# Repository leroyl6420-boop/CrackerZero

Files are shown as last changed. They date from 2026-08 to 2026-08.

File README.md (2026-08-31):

# CrackerZero
A portable, Raspberry Pi 0-powered cyberdeck! My first cyberdeck too (: it's thin and light like a cracker

The Cracker Zero will be my first cyberdeck! The reason as to why I chose a Pi 0 instead of a Pi 4 or 5 is because I wanted extra space and budget to make a custom keyboard. It'll be nothing fancy, just a couple of push buttons and a joystick on a perfboard, but I can say that it is my own (: I'm planning on running some kind of Linux.

# Wiring Diagram

Wiring diagram for the Pi:

| Left row | Function | Use | Right row | Function | Use |
|---:|---|---|---:|---|---|
| **1** | 3.3 V | SCREEN | **2** | 5 V | SCREEN / same 5 V rail as power input |
| **3** | GPIO 2 / SDA | SCREEN | **4** | 5 V | SCREEN / same 5 V rail as power input |
| **5** | GPIO 3 / SCL | SCREEN | **6** | GND | SCREEN |
| **7** | GPIO 4 | SCREEN | **8** | GPIO 14 / TXD | SCREEN |
| **9** | GND | SCREEN | **10** | GPIO 15 / RXD | SCREEN |
| **11** | GPIO 17 | SCREEN | **12** | GPIO 18 | SCREEN |
| **13** | GPIO 27 | SCREEN | **14** | GND | SCREEN |
| **15** | GPIO 22 | SCREEN | **16** | GPIO 23 | SCREEN |
| **17** | 3.3 V | SCREEN | **18** | GPIO 24 | SCREEN |
| **19** | GPIO 10 / MOSI | SCREEN | **20** | GND | SCREEN |
| **21** | GPIO 9 / MISO | SCREEN | **22** | GPIO 25 | SCREEN |
| **23** | GPIO 11 / SCLK | SCREEN | **24** | GPIO 8 / CE0 | SCREEN |
| **25** | GND | SCREEN | **26** | GPIO 7 / CE1 | SCREEN |
| **27** | GPIO 0 / ID_SD | Leave unused | **28** | GPIO 1 / ID_SC | Leave unused |
| **29** | GPIO 5 | Available | **30** | GND | Available |
| **31** | GPIO 6 | Available | **32** | GPIO 12 | Available |
| **33** | GPIO 13 | Available | **34** | GND | Available |
| **35** | GPIO 19 | Available | **36** | GPIO 16 | Available |
| **37** | GPIO 26 | Available | **38** | GPIO 20 | Available |
| **39** | GND | Available | **40** | GPIO 21 | Available |

A 22 AWG wire will be soldered onto the 5v wires from the TP4056 module. The GND will be soldered to one of the empty ground pins. I really wish they'd make the screen use only one 5V pin :P

Wiring diagram for the CH32X035 devboard keyboard:

| LEFT SIDE | USE | RIGHT SIDE | USE |
|---|---|---|---|
| 5V | USB power | GND | Ground |
| GND | Ground | PC19 | Unused |
| 3V3 | KY-023 VCC | PB12 | Button 1 |
| PA0 | Joystick X | PC18 | Unused |
| PA1 | Joystick Y | PB11 | Button 2 |
| PA2 | Joystick Click | PB3 | Button 3 |
| PA3 | Layer LED | PB1 | Button 4 |
| PA4 | Spare | PB0 | Button 5 |
| PA5 | Spare | PA7 | Button 6 |
| — | — | PA6 | Spare |

I chose not to CAD a case for the keyboard to get the see the art from Cyao on the CH32X035 :D

# CAD

There wasn't much CADing to do for the Cracker Zero! I just make sure that I knew where to put all the parts, here:

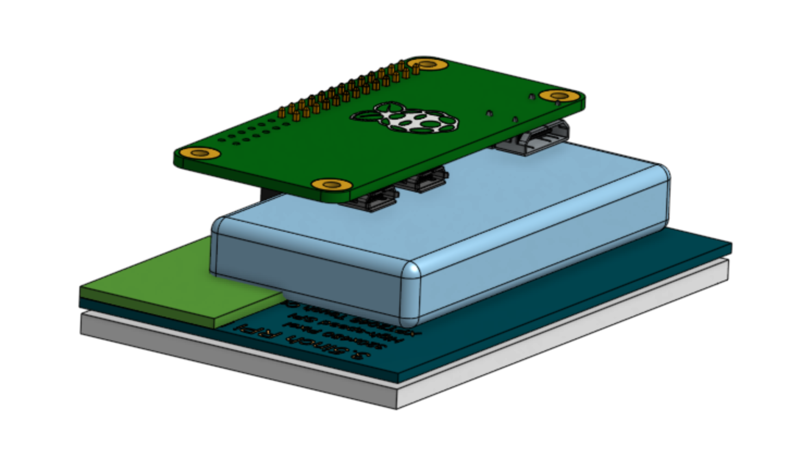
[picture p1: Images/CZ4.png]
An image of the caseless Cracker Zero


And I made a case for the Pi and the screen, here:

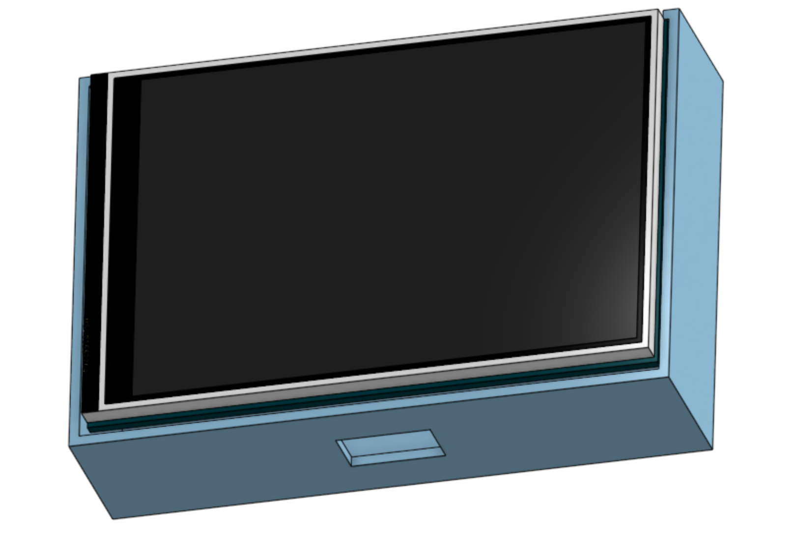
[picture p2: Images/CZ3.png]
The Cracker Zero in its case


Of course, I had to CAD the cute little keyboard

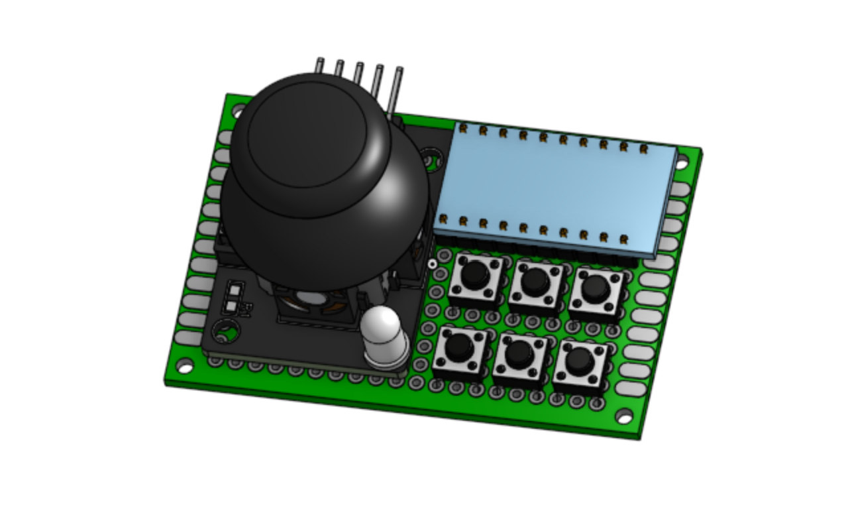
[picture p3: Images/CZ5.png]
An image of the Cracker Zero's custom keyboard


# Assembly

Assembling the Cracker Zero won't be very hard. Just find two 13-pin-long pin headers and solder them onto the first 13 pin slots of both rows on the Pi 0. Solder the Lipo's spliced wires onto the protection module's BAT+ and BAT- pads, and solder the protection module's Input/Output +/- pads to the TP4056 module's BAT+/- pins. Wire the TP4056's OUT+ to one of the Pi's 5V pins (using the latching button), and wire the OUT- to any of the Pi's GNDs. The Cracker Zero charges using micro USB (I know I know diabolical). Solder the keyboard according to the wiring diagram, and connect it to the Pi's data micro USB port using a USB-C to micro USB power/data cable. 

# AI Use

AI was used to find good parts/deals.

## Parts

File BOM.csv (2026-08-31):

Part | Quantity | Cost | Link
Raspberry Pi Zero W | 1 | $36.99 | https://www.amazon.com/EC-Buying-Pi-Zero-Development/dp/B0FN4CN7TM
ch32x035 Devboard | 1 | Already Owned
3.5 Inch 480x320 Display | 1 | $17.99 | https://www.amazon.com/Hosyond-480x320-Screen-Display-Raspberry/dp/B0BJDTL9J3
6x4cm Perfboard | 1 | $7.99 | https://www.amazon.com/Chanzon-Double-Sided-Board-Sizes/dp/B07LF78ZY3
USBC to Micro USB Cable | 1 | $5.69 | https://www.amazon.com/FEMORO-Adapter-Braided-Transfer-Compatible/dp/B0CMLS2MB1?hvadid=816679433751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
Latching Button | 1 | $9.98 | https://www.amazon.com/DMWD-12-Pack-Latching-Pre-soldered-Self-Locking/dp/B0D4D8DQJD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
Battery Protection Module | 1 | $5.99 | https://www.amazon.com/DIANN-Charger-Protection-Lithium-Battery/dp/B0B4D1D74V
Battery Charging Module | 1 | $9.89 | https://www.amazon.com/Battery-Charger-Discharge-Integrated-Lithium/dp/B098989NRZ
3.7v Lipo | 1 | $9.99 | https://www.amazon.com/JLJLUP-Rechargeable-Integrated-Protection-Development/dp/B0FH9XHXRT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
32GB Micro SD Card | 1 | $22.80 | https://www.amazon.com/SanDisk-Ultra%C2%AE-microSDHC-120MB-Class/dp/B08L5HMJVW
22AWG Solid Core Wire | N/A | $11.98 | https://www.amazon.com/BNTECHGO-Electric-Gauge-Tinned-Copper/dp/B07JMVX22G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
Tax |  | $11.18
Total |  | $155.46

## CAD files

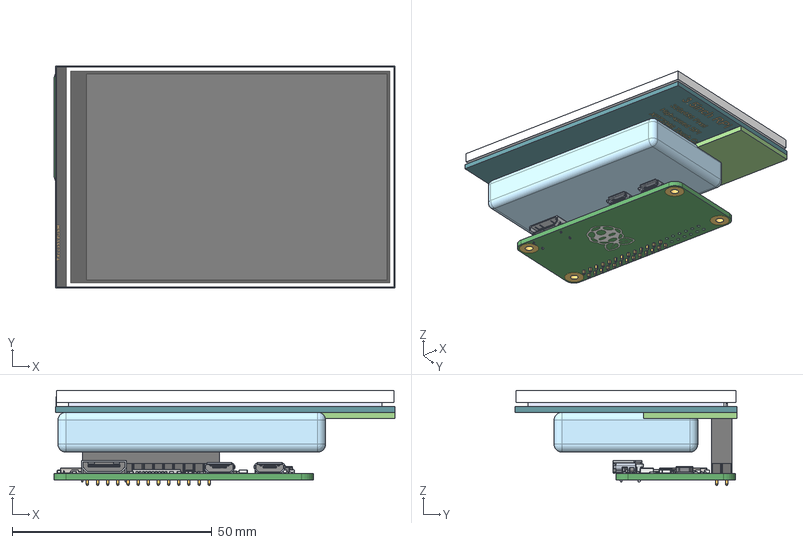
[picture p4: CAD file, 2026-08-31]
CAD/Assembly 1.step
85.4 x 55.5 x 23.9 mm
3.5inch RPi LCD board-1-solid1
PBD 26-1-solid1
10-Pin Header - Male - 2.54mm:1__Körper1 x 4
Board:1__Körper1
terminal:1__Körper1 x 10
socket_plate:1__Körper1 x 2
shield:1 x 24
socket_housing:1__Körper1 x 2
Pin1:1__Körper1 x 18
Housing2:1__Körper1
Pin2:1__Körper1
Housing:1__Körper1
Shielding:1__Körper1
Micro SD slot v1:1__Körper7
Micro SD slot v1:1__Körper2
Micro SD slot v1:1__Körper9
Micro SD slot v1:1__Körper8
Micro SD slot v1:1__Körper1
Micro SD slot v1:1__Körper10
Micro SD slot v1:1__Körper3
Micro SD slot v1:1__Körper5
Micro SD slot v1:1__Körper4
Micro SD slot v1:1__Körper6
Components:1__Körper1
CAPC-0805-T0.95-BN v1:1__Körper1 x 7
CAPC-0402-T0.55-BN v1:1__Körper1 x 49
INDC-0402 v1:1__Körper1 x 6
INDC-0603 v1:1__Körper1 x 2
CAPC-0603-T0.9-BN v1:1__Körper1 x 2
Components:1__Körper2
RESC-0402 v1:1__Körper2 x 14
RESC-0402 v1:1__Körper3 x 14
RESC-0402 v1:1__Körper1 x 14
CAPC-1206-T1.4-BN v1:1__Körper1
SRN4018 v1:1__Körper4
SRN4018 v1:1__Körper2
SRN4018 v1:1__Körper5
SRN4018 v1:1__Körper3
SRN4018 v1:1__Körper1

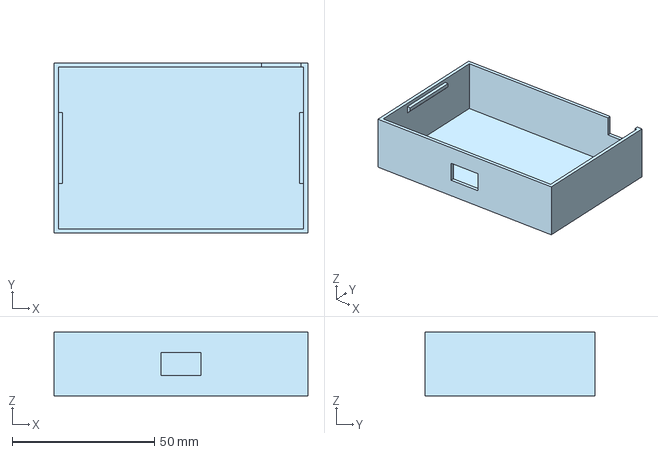
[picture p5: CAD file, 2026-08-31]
Production/Case.step
89.4 x 59.9 x 22.5 mm

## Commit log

2026-08-30 Replace Seeed XIAO RP2040 with ch32x035 Devboard
    [BOM.csv]
2026-08-31 Add wiring diagram section to README
    Added wiring diagram for the Raspberry Pi 0 setup.
2026-08-31 Replace case image in README
    Updated the image of the Cracker Zero in its case.
